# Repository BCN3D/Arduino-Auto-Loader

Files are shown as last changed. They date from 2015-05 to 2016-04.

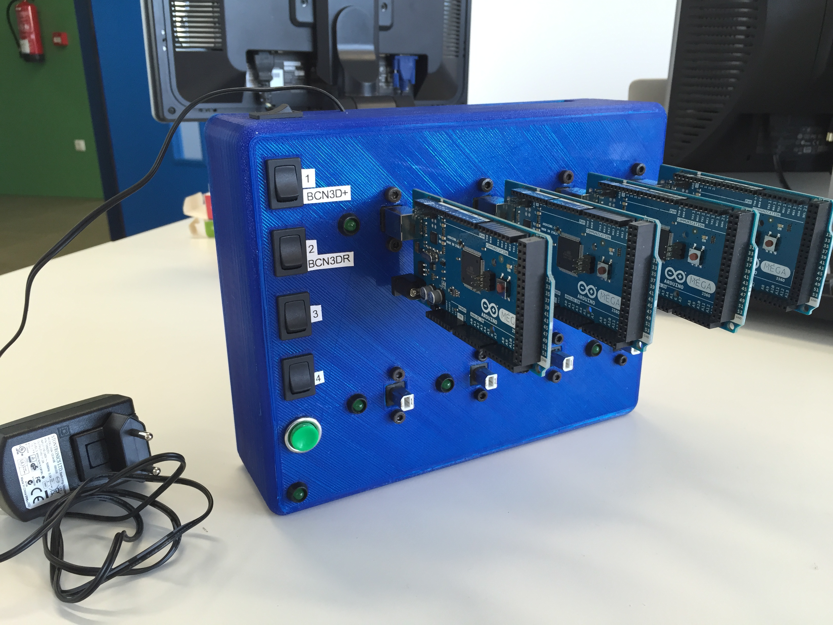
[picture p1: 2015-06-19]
img/IMG_1424.JPG

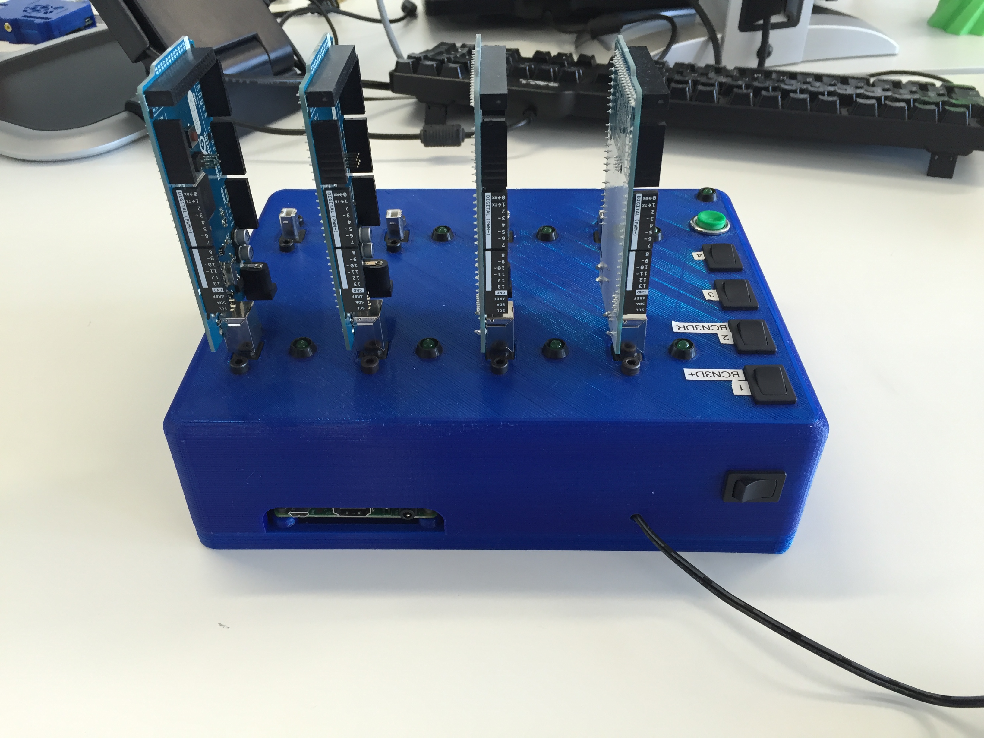
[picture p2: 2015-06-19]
img/IMG_1423.JPG

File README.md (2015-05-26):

# Arduino Auto Loader
Here at **BCN3DTechnologies**, all of our 3D Printers are shipped with an Arduino on its heart. So obviously, we need to load the firmware to a bunch of microcontrollers. That's a tedious work to do because it takes us about 1,5 min to load a single firmware with the Arduino IDE. Compile, Load, Verify and Repeat.
If you take that time and multiply it by the number of printers we sell in a month, it's a lot of time wasted for the person in front of the computer. So we decided to make something about it.

##How it works
It couldn't be easier. Using a Raspberry Pi as a single board computer, we attached a 10 port USB hub and then plug in the Arduinos using an extension cable. The Raspberry detects the Arduinos and it uploads the code to the arduinos sequentially using *avrdude* commands.
Of course, as we carry different 3D printers, we have toggle switches to be able to select the correct firmware and a LED to every Arduino indicating if everything went well.
Then all the electronics are packaged in a 3D printed enclosure of course!
##Bill of materials
The list of things you'll need to replicate this project:
* 1x Raspberry Pi. We've used a Model A+ but any will fit. 
* 1x 5V power supply
* 8x USB Extension cable. about 20 cm long.
* 8x green LEDs with their current limiting resistor (330 Ohms)
* A couple of meters of 22AWG wire of different colors.
* 4 toggle switches. We used power supply ones.
* 2 push buttons
* Acces to a 3D Printer

Optionally we've included a wifi dongle to access the raspberry via SSH if needed to do some maintenance.
The total cost of the project is about 50€ including the raspberry.

##Code
The code is made in Python and you can download from the repository. We've configured the raspberry in order to run the script just after the powerup. You can follow [this instructions](http://www.raspberry-projects.com/pi/pi-operating-systems/raspbian/auto-running-programs) to do that.
You'll also need to configure the raspberry to start without login like [here](http://stackoverflow.com/questions/17830333/start-raspberry-pi-without-login).
If you want to do some wireless maintenance you'll need to configure the ssh server too. This is [how it's done](https://www.raspberrypi.org/documentation/remote-access/ssh/).

##Printed Parts
You can download all the **STL** files if you want to print our design or make your own.
The files are: 
* Box.stl
* Top Box.stl
* USB Fixer.stl

##Milestones
We've managed to improve the way we load the firmware to our electronics. It will serve to our future electronics as well. 

Now we can load a 120KB firmware to an arduino in 16 seconds. So in the time we upload a firmware to an Arduino with the original IDE we can upload 8! 

It's also a self working system and there's no need of a person looking after it.

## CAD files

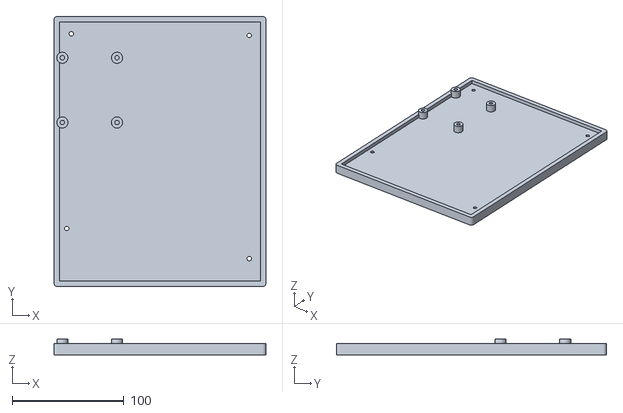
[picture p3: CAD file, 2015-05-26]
STL files/Top Box.stl
190.0 x 242.0 x 14.0

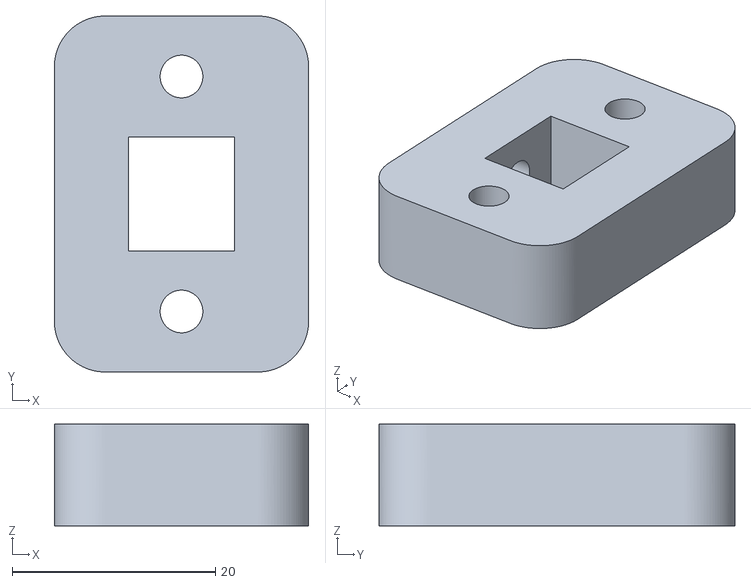
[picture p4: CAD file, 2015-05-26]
STL files/USB Fixer.stl
25.0 x 35.0 x 10.0

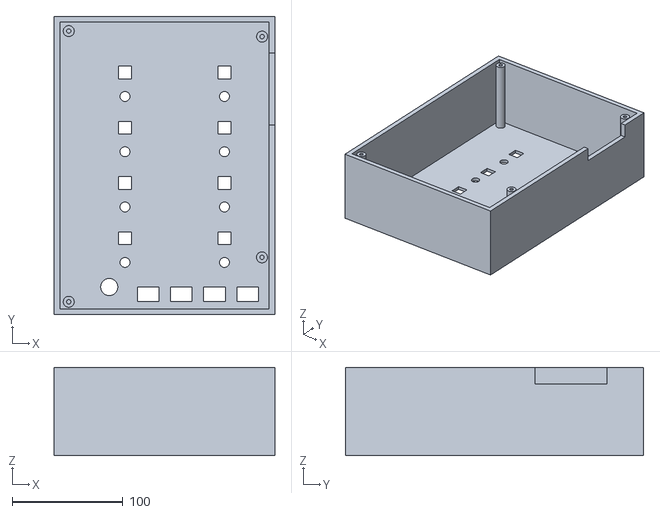
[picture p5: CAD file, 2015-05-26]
STL files/Box.stl
200.0 x 270.0 x 80.0

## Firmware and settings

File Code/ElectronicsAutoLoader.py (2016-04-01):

# -*- encoding: utf-8 -*-
#Electronics Auto Loader - Enric Gómez Pitarch & Marc Cobler
#BCN3D Technologies - Fundacio CIM
#
#Python program that can upload the firmware up to 8 boards in series
#It has 4 rocker switches to select the firmware to upload and a load button to
#start the sequence. First it ckecks for internet connection and pulls updates from github.
#It uses avrdude for .hex upload

#PIN Connections
#SWITCH 1		-->		PIN11 - GPIO17
#SWITCH 2		-->		PIN13 - GPIO27
#SWITCH 3		-->		PIN15 - GPIO22
#SWITCH 4		-->		PIN16 - GPIO23
#LOAD BUTTON	-->		PIN18 - GPIO24
#LED1			-->		PIN23 - GPIO11
#LED2			-->		PIN29 - GPIO5
#LED3			-->		PIN31 - GPIO6
#LED4			-->		PIN33 - GPIO13
#LED5			-->		PIN32 - GPIO12
#LED6			-->		PIN36 - GPIO16
#LED7			-->		PIN38 - GPIO20
#LED8			-->		PIN40 - GPIO21

import RPi.GPIO as GPIO
import time
import os
import sys
import socket
from serial.tools import list_ports
from clint.textui import colored 

filesRepoPath 	= ('/home/pi/BCN3D-Utilities')
repoPath 		= ('/home/pi/arduino-auto-loader')
BCN3DPlusPath 	= ('/home/pi/BCN3D-Utilities/Firmware\ uploader\ scripts/Files/BCN3D_Plus_latest.hex')
BCN3DRPath 		= ('/home/pi/bcn3d-utilities/Firmware\ uploader\ scripts/Files/BCN3D_R_latest.hex')
BCN3DSigmaPath 	= ('/home/pi/bcn3d-utilities/Firmware\ uploader\ scripts/Files/BCN3D_Sigma_Firmware_latest.hex')

#LEDS
LED1 = 11
LED2 = 5
LED3 = 6 
LED4 = 13
LED5 = 12
LED6 = 16
LED7 = 20
LED8 = 21

def haveInternet():
	REMOTE_SERVER = "www.google.com"
	try:
		host = socket.gethostbyname(REMOTE_SERVER)
		s = socket.create_connection((host, 443))
		return True
	except:
		pass
	return False


def syncGithub():
	#Update the repositor
	if haveInternet():
		print (colored.green("=============Internet is ON!================"))
		try:
			print "Getting updates from github"
			os.chdir(repoPath)
			currentDirectory = os.getcwd()
			print "the current directory is: %s" % currentDirectory
			os.system("git pull")
			os.chdir(filesRepoPath)
			os.system("git pull")
		except:
			print (colored.red("Something went wrong, check you internet connection"))
			pass
	else:
		print (colored.red("==========No internet, no github sync=========="))
        

def manageInputs():
        print "Setting the input switches"
        GPIO.setwarnings(False)
        GPIO.setmode(GPIO.BCM)
        #Set Pull ups to pins
        GPIO.setup(24, GPIO.IN, pull_up_down=GPIO.PUD_UP)
        GPIO.setup(17, GPIO.IN, pull_up_down=GPIO.PUD_UP)
        GPIO.setup(27, GPIO.IN, pull_up_down=GPIO.PUD_UP)
        GPIO.setup(22, GPIO.IN, pull_up_down=GPIO.PUD_UP)
        GPIO.setup(23, GPIO.IN, pull_up_down=GPIO.PUD_UP)
        #Read the inputs for the first time
        input_state_24 = GPIO.input(24)
        input_state_17 = GPIO.input(17)
        input_state_27 = GPIO.input(27)
        input_state_22 = GPIO.input(22)
        input_state_23 = GPIO.input(23)
        
def comPortsInfo():
	#getting the comports
	global ports
	ports=list_ports.comports()
	#print ports
	print "There are %d available comports: " % len(ports)
	#list the comports available
	for port in ports:
		print (colored.green(port[0]))

def printButtonStatus(switch1, switch2, switch3, switch4):
	print "Switch 1 is set to: %d" % switch1
	print "Switch 2 is set to: %d" % switch2
	print "Switch 3 is set to: %d" % switch3
	print "Switch 4 is set to: %d" % switch4
	
def startUpLEDS():
	#Just a sequence of LEDs to know that the system is running the program
	#We need root access to manipulate the GPIO!
	print "Lighting some LEDs..."
	for x in range(0,4):
	     GPIO.setup(21, GPIO.OUT)
	     GPIO.output(21, GPIO.HIGH)
	     GPIO.setup(13, GPIO.OUT)
	     GPIO.output(13, GPIO.HIGH)
	     time.sleep(0.1)
	     #print "."
	     GPIO.output(21, GPIO.LOW)
	     GPIO.output(13, GPIO.LOW)
	     GPIO.setup(20, GPIO.OUT)
	     GPIO.output(20, GPIO.HIGH)
	     GPIO.setup(6, GPIO.OUT)
	     GPIO.output(6, GPIO.HIGH)
	     time.sleep(0.1)
	     #print "."
	     GPIO.output(20, GPIO.LOW)
	     GPIO.output(6, GPIO.LOW)
	     GPIO.setup(16, GPIO.OUT)
	     GPIO.output(16, GPIO.HIGH)
	     GPIO.setup(5, GPIO.OUT)
	     GPIO.output(5, GPIO.HIGH)
	     time.sleep(0.1)
	     #print "."
	     GPIO.output(16, GPIO.LOW)
	     GPIO.output(5, GPIO.LOW)
	     GPIO.setup(12, GPIO.OUT)
	     GPIO.output(12, GPIO.HIGH)
	     GPIO.setup(11, GPIO.OUT)
	     GPIO.output(11, GPIO.HIGH)
	     time.sleep(0.1)
	     #print "."
	     GPIO.output(12, GPIO.LOW)
	     GPIO.output(11, GPIO.LOW)
	     time.sleep(0.1)

def turnOnLED(pin):
	GPIO.output(pin, GPIO.HIGH)
	
def turnOffLED(pin):
	GPIO.output(pin, GPIO.LOW)
	
def turnOffAllLEDS():
	turnOffLED(LED1)
	turnOffLED(LED2)
	turnOffLED(LED3)
	turnOffLED(LED4)
	turnOffLED(LED5)
	turnOffLED(LED6)
	turnOffLED(LED7)
	turnOffLED(LED8)

def loadFirmware(firmware):
	x = 0
	for port in ports:
		print "loading %s firmware in Port %s" % (firmware, port[0])
		os.system("avrdude -p m2560 -c avrispmkII -V -D -P %s -U flash:w:%s:i" % (port[0], firmware))
		#turnOnLED(LED + x)
	
	turnOffAllLEDS()
	print (colored.green("============ALL BOARDS LOADED==============="))	
	
	

def checkButtons(channel):
	#Read the status of the switches and buttons
	try:
		print "Reading the inputs..."
		input_state_17 = GPIO.input(17) #Interruptor 1 - BCN3D+
		input_state_27 = GPIO.input(27) #Interruptor 2 - BCN3DR
		input_state_22 = GPIO.input(22) #Interruptor 3 - BCN3DSigma
		input_state_23 = GPIO.input(23) #Interruptor 4 - Unused
		printButtonStatus(input_state_17, input_state_27, input_state_22, input_state_23)
		
		if input_state_17 == True and input_state_27 == False and input_state_22 == False and input_state_23 == False:
			#Interruptor 1 pressed, Loading BCN3D+ firmware
			print "Loading BCN3D Plus Firmware"
			loadFirmware(BCN3DPlusPath)				
						   
		if input_state_17 == False and input_state_27 == True and input_state_22 == False and input_state_23 == False:
			#Interruptor 2 pressed, Loading BCN3DR firmware+
			print "Loading BCN3DR Firmware"
			loadFirmware(BCN3DRPath)

		if input_state_17 == False and input_state_27 == False and input_state_22 == True and input_state_23 == False:
			#Interruptor 3 pressed, Loading BCN3DSigma firmware
			print "Loading BCN3D Sigma Firmware"
			loadFirmware(BCN3DSigmaPath)
													
		#If switches 1,2,3 are selected and the load button pressed --> REBOOT
		if input_state_17 == True and input_state_27 == True and input_state_22 == True and input_state_23 == False:
			print 'Rebooting...'
			startUpLEDS()
			os.system("sudo reboot")
		#If switches 1,2,4 are selected and the load button pressed --> SHUTDOWN
		if input_state_17 == True and input_state_27 == True and input_state_22 == False and input_state_23 == True:
			print 'Powering off the system...'
			startUpLEDS()
			os.system("sudo poweroff")
			
	except KeyboardInterrupt:
		print "program closed by user"
		GPIO.cleanup()
		sys.exit()
	except:
		print "Other error or exception ocurred!"
		GPIO.cleanup()
		sys.exit()  
	
    
#Main program
def main():
	syncGithub()
	manageInputs()
	startUpLEDS()
	comPortsInfo()
	#Callback function in PIN 24. Whenever a Falling Edge is detected, run the checkButtons Function
	GPIO.add_event_detect(24, GPIO.FALLING, callback=checkButtons, bouncetime=300)  
	while True:
		time.sleep(0.1)
		#print (colored.green("Waiting for the load button..."))                                     
		
#Just the regular boilerplate to start the program
if __name__ == '__main__':
	print "Starting the Electronics Auto Loader...!"
	main()
